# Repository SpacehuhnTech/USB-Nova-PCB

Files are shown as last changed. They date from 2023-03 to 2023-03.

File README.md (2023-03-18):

# USB-Nova-PCB
USB Nova Hardware Design Files

USB Nova is a cute little USB “drive” that acts as a keyboard, much like the USB Rubber Ducky, WiFi Duck, and other BadUSBs.

Learn about the Project at [usbnova.com](https://usbnova.com).  
Buy one at [spacehuhn.store](https://spacehuhn.store/products/usb-nova).  

USB Nova Picture

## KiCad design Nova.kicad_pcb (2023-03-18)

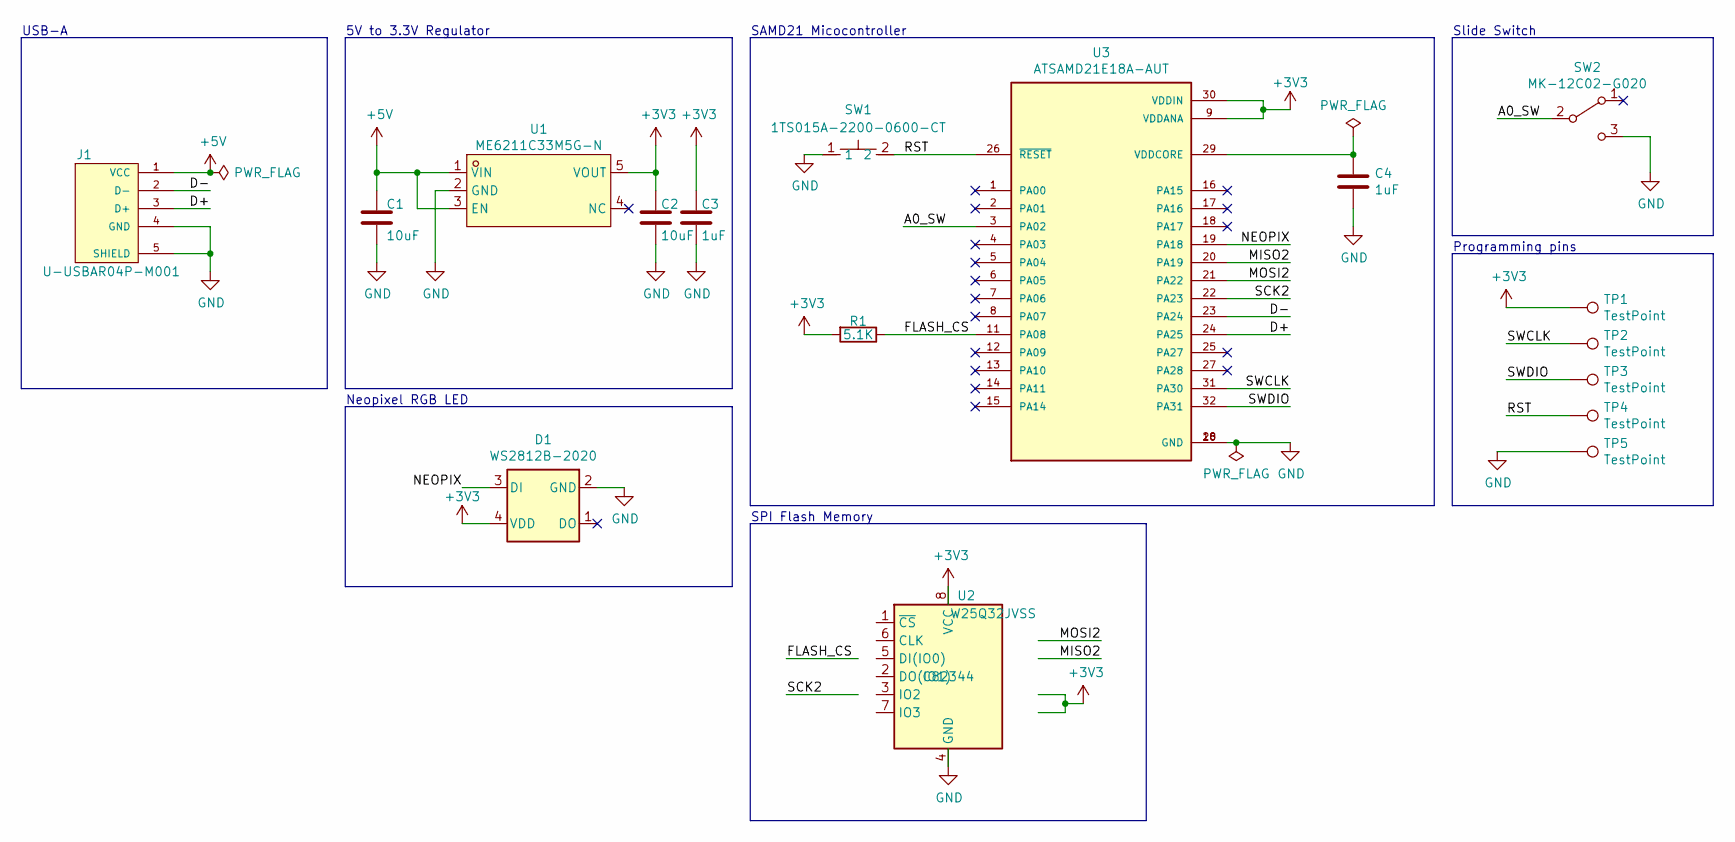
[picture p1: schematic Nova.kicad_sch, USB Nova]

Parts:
C1, C2: 10uF; C_0603_1608Metric
C3, C4: 1uF; C_0603_1608Metric
D1: WS2812B-2020; LED-SMD_4P-L2.0-W2.0-TL_WS2812B-2020; Part# WS2812B-2020; LCSC# C965555
J1: U-USBAR04P-M001; USB-A_Plug_THT_U-USBAR04P-M001; Part# U-USBAR04P-M001
R1: 5.1K; R_0603_1608Metric
SW1: 1TS015A-2200-0600-CT; SW-SMD_L3.0-W2.0-LS3.5; MPN C398748; LCSC Part C398748
SW2: MK-12C02-G020; SW_MK-12C02-G020; MPN C963206; LCSC# C963206
TP1, TP2, TP3, TP4, TP5: TestPoint; TestPoint_Pad_D1.5mm
U1: ME6211C33M5G-N; SOT-25-5_ME6211C33M5G; MPN C82942; LCSC# C82942
U2: W25Q32JVSS; SOIC-8_5.23x5.23mm_P1.27mm; MPN C82344
U3: ATSAMD21E18A-AUT; Part# ATSAMD21E18A-AU; Mouser# 556-ATSAMD21E18A-AU

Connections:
+3V3: C2.1, C3.1, D1.4 (VDD), R1.2, TP1.1, U1.5 (VOUT), U2.8 (VCC), U3.9 (VDDANA), U3.30 (VDDIN)
+5V: C1.1, J1.1 (VCC), U1.1 (VIN), U1.3 (EN)
/A0_SW: SW2.2 (B), U3.3 (PA02)
/D+: J1.3 (D+), U3.24 (PA25)
/D-: J1.2 (D-), U3.23 (PA24)
/FLASH_CS: R1.1, U3.11 (PA08)
/MISO2: U3.20 (PA19)
/MOSI2: U3.21 (PA22)
/NEOPIX: D1.3 (DI), U3.19 (PA18)
/RST: SW1.2, TP4.1, U3.26 (~RESET)
/SCK2: U3.22 (PA23)
/SWCLK: TP2.1, U3.31 (PA30)
/SWDIO: TP3.1, U3.32 (PA31)
GND: C1.2, C2.2, C3.2, C4.2, D1.2 (GND), J1.4 (GND), J1.5 (SHIELD), SW1.1, SW2.3 (C), TP5.1, U1.2 (GND), U2.4 (GND), U3.10 (GND), U3.28 (GND)
unnamed: C4.1, U3.29 (VDDCORE)

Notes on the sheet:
Neopixel RGB LED
USB-A
SAMD21 Micocontroller
Slide Switch
Programming pins
5V to 3.3V Regulator
SPI Flash Memory

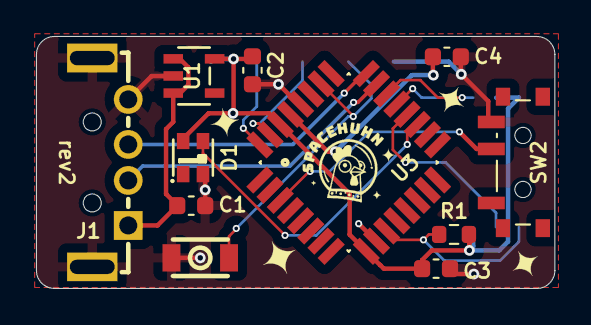
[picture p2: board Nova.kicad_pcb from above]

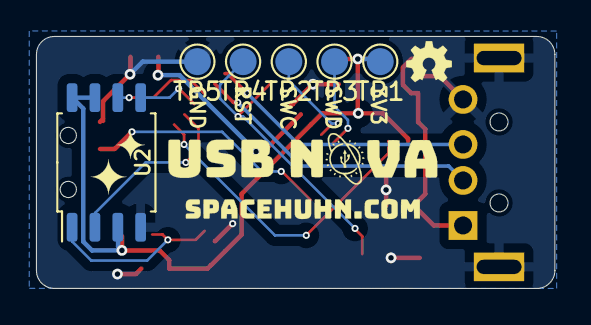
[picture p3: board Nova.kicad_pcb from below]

Board: 2 copper layers, 28.8 x 14.0 mm, 17 parts (6 on the bottom side), 12 nets.
